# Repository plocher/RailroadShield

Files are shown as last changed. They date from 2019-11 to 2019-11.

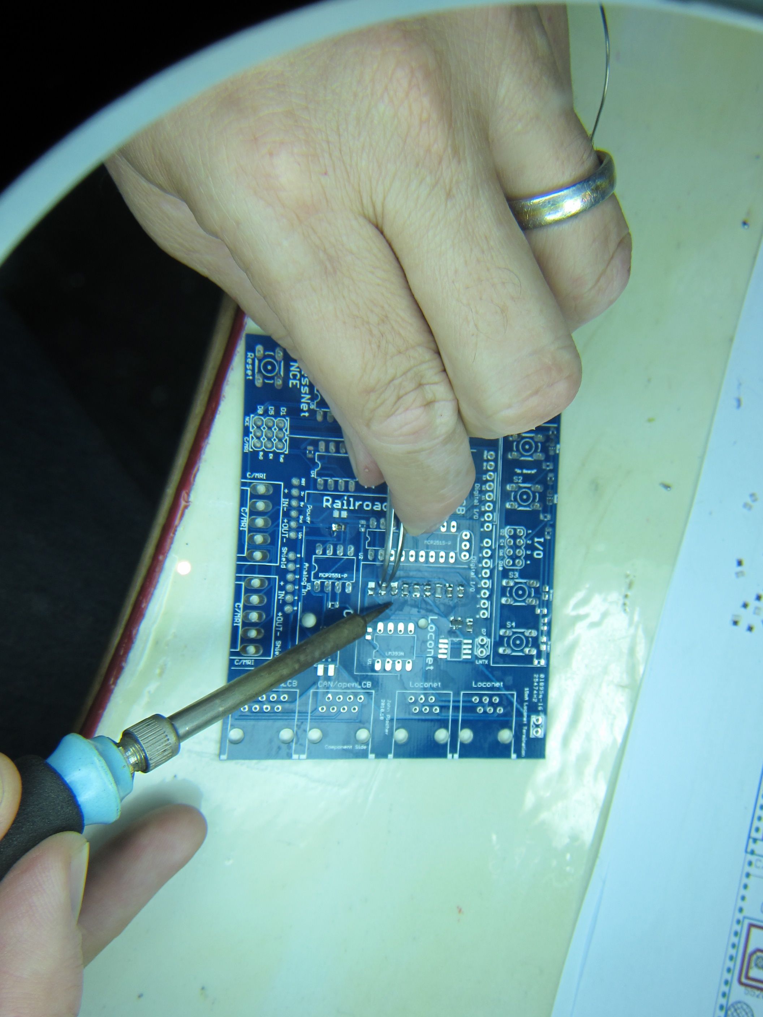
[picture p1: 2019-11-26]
RailroadShield-06.jpg

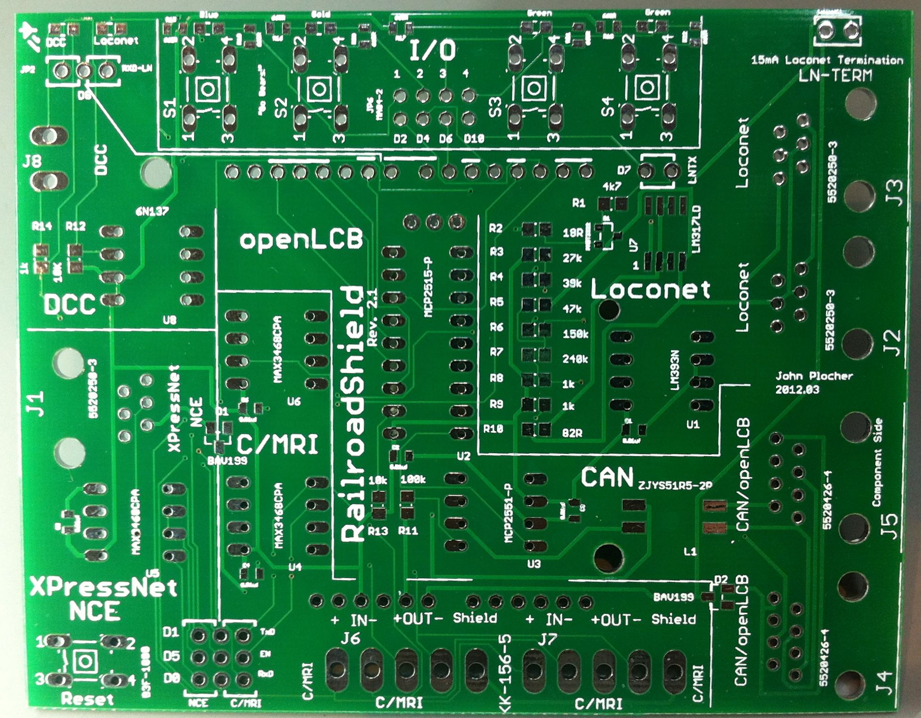
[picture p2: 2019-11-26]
RailroadShield-13.jpg

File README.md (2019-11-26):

# RailroadShield
## License: CERN Open Hardware Licence v1.2

A community prototyping board to help with the bringup and maturation of OpenLCB.

Status: Prototypes fab'd and assembled, runs simple OpenLCB sketches, more testing underway in the OpenLCB community...

This project is an Arduino shield for Loconet, CAN and
[http://www.olcb.org/ OpenLCB] experimentation.  It is based on an
earlier set of experiments that only supported CAN and Loconet as
part of a custom 'duino stack which was used to build a [[ControlPoint]]
demo for the PCR Coast Division meet early in September, 2010.

I also spun solderless breadboard versions of the CANBusBreadboard
and LoconetBreadboard; the Loconet board works fine, but I have not
yet (2010) built and tested the CAN board.

The prototype served its purpose - it helped prove out the design
pattern of a local control point node that uses a local Loconet to
monitor occupancy detectors, turnouts and other "vital" logic as
well as control signals associated with the interlocking.  I built
a small handful of 8- and 16-bit I2C based I/O expander boards
(think mini-C/MRI) to make interfacing with control panels and LEDs
easier, but the power draw of 30 to 60 LEDs - even at 10mA ea - is
almost too much for the simple heatsinked 7805 linear regulator I
designed into the main board.  Better to use a distributed power
supply design, which means another design/fab cycle and more boards
in my junk drawer :-)

As in the real world, the control point passed Controls and Indications
back and forth along a code line; in the 1.0 demo, I used OPC_PEER_XFER
Loconet packets to emulate a code line; the next step is to use
CAN/openLCB instead.

The RailroadShield board is based on an expanded footprint Arduino
Shield template so that Decimila, Uno and Duemilanove boards can
easily be used with it.

This design has hardware support for

  * DCC  on D8,
  *  * See [http://www.nmra.org/standards/DCC/standards_rps/DCCStds.html NMRA DCC Standards] documentation
  * Loconet (RXD on D8, Lnet TXD on D7)
  *  * See Digitrax's [Loconet Personal Edition](http://www.digitrax.com/ftp/loconetpersonaledition.pdf)
  * CAN/openLCB using MCP2515 & MCP2551 on D13-D11,D9 & D3
  *  * See [OpenLCB info](http://openlcb.org/trunk/prototypes/Hobbyists.html)
  * RS485 full duplex/2 wire (NCE & XPressNet) or half duplex/4 wire (C/MRI) using the built in UART on D0/D1 with TX enable on D5
  *  * See Lenz's XpressNet: [Specification](http://www.lenz.com/manuals/xpressnet/xpressnet.pdf) and
  *  * NCE's cab bus [on page 32 of the Power Pro System Reference Manual](http://www.ncedcc.com/images/stories/manuals/sysman07.pdf)
  * 4 buttons+LEDs for simple I/O testing.

Let me know if you develop sketches or libraries for the above and
I will update this page with links.  Better yet, contribute the
code back to the openlcb.org openLCB project.

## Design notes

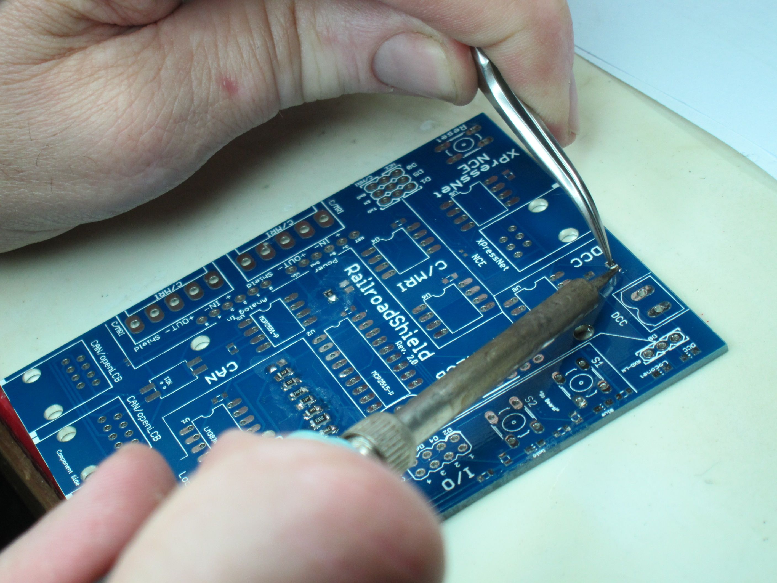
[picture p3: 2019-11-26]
RailroadShield-09.jpg

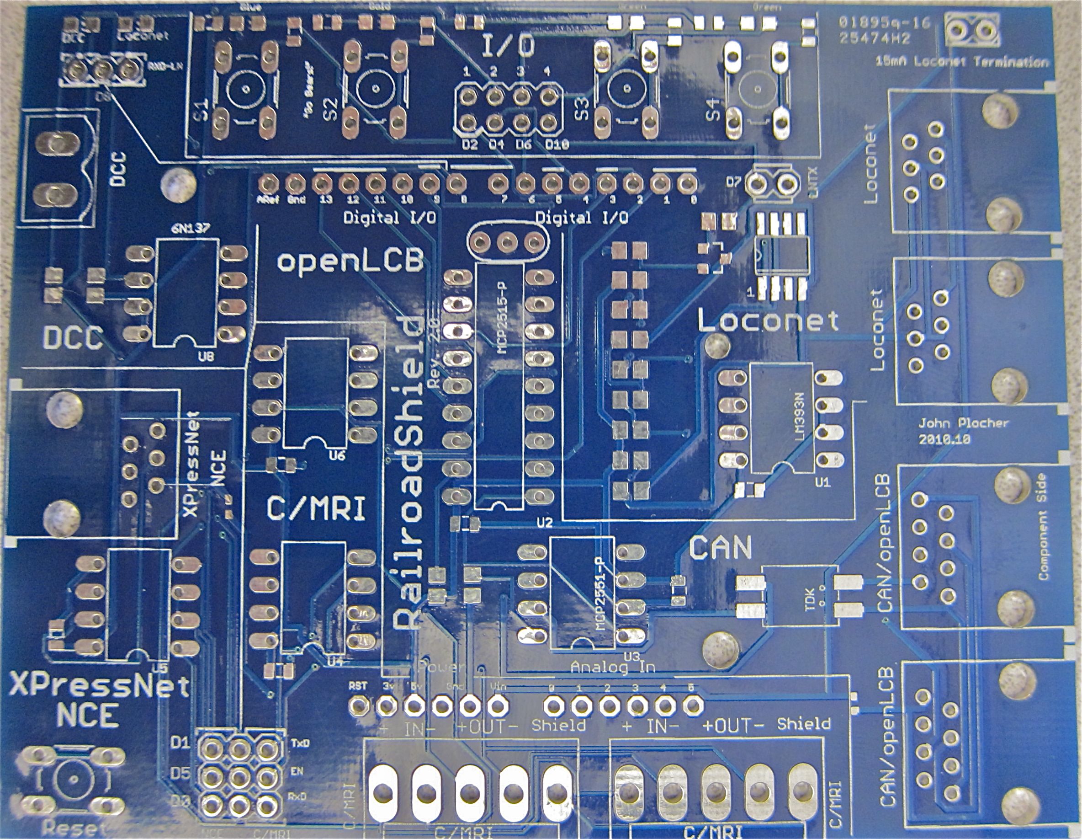
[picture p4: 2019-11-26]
RailroadShield-03.jpg

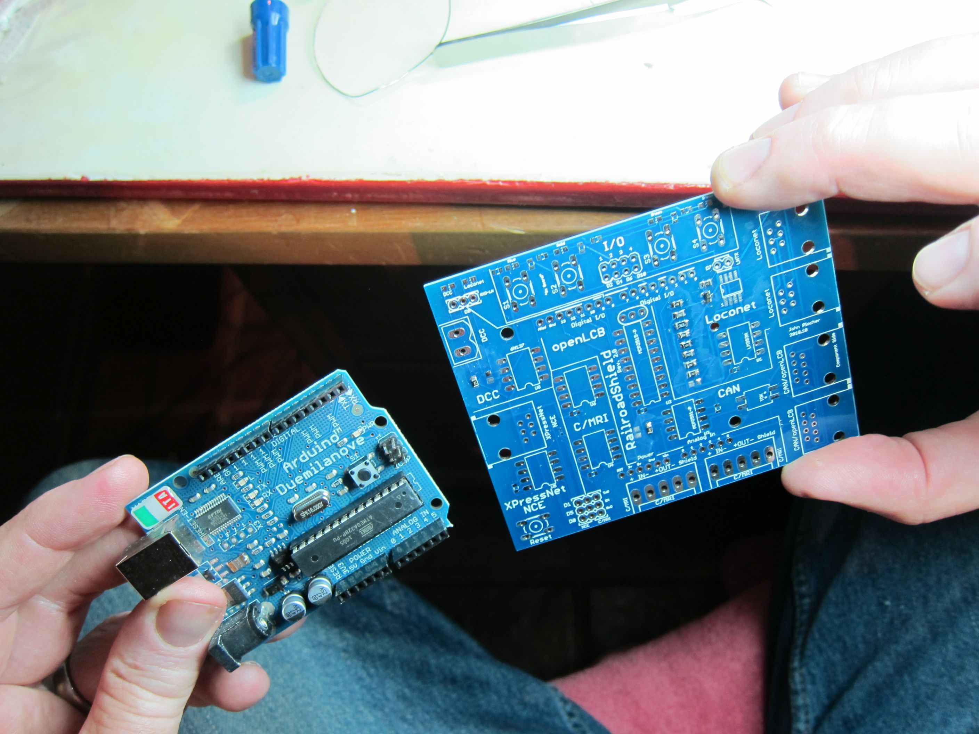
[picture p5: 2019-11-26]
RailroadShield-08.jpg

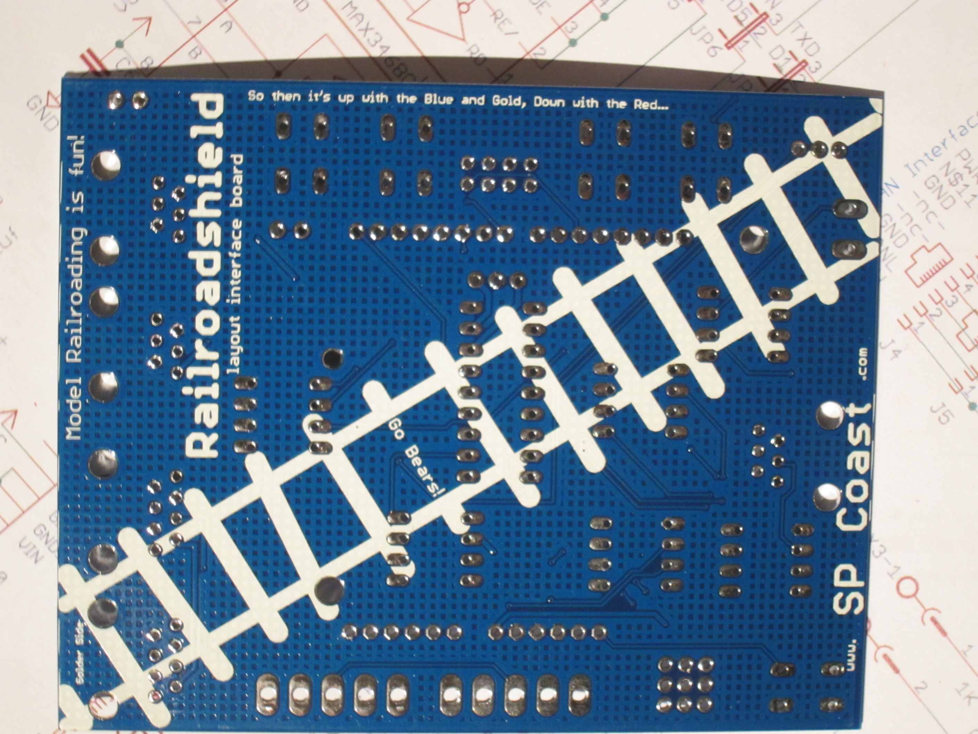
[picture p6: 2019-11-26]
RailroadShield-11.jpg

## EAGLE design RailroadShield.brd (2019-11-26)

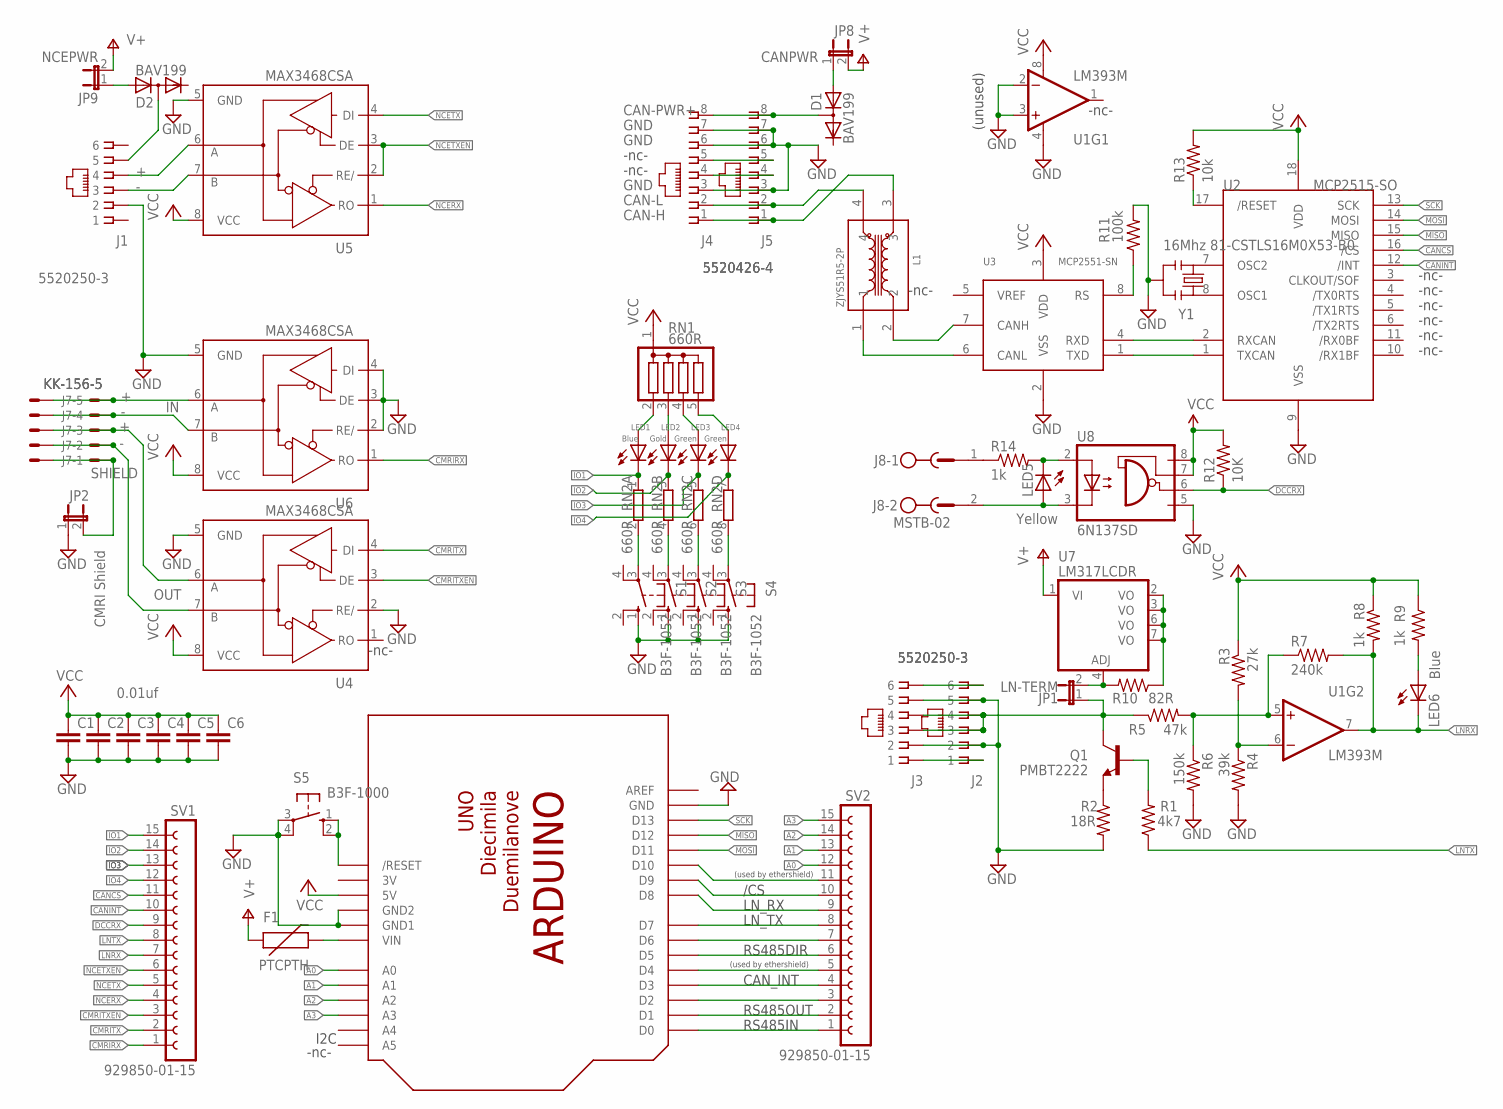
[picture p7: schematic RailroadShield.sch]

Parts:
C1, C2, C3, C4, C5, C6: 0.01uf; 0805
D1, D2: BAV199; SOT23
F1: PTCPTH; PTC
J1, J2, J3: 5520250-3; RJ11-NO_SHIELD
J4, J5: 5520426-4; RJ45-NO-SHIELD
J6, J7: KK-156-5
J8: MSTB-02; MSTBV2
JP1: LN-TERM; 1X02_LOCK
JP2: CMRI Shield; 1X02_LOCK
JP8: CANPWR; 1X02_LOCK
JP9: NCEPWR; 1X02_LOCK
L1: ZJYS51R5-2P; ZJYS
LED1, LED6: Blue; CHIP-LED0805
LED2: Gold; CHIP-LED0805
LED3, LED4: Green; CHIP-LED0805
LED5: Yellow; CHIP-LED0805
Q1: PMBT2222; SOT23-3
R1: 4k7; R0805
R2: 18R; R0805
R3: 27k; R0805
R4: 39k; R0805
R5: 47k; R0805
R6: 150k; R0805
R7: 240k; R0805
R8, R9, R14: 1k; R0805
R10: 82R; R0805
R11: 100k; R0805
R12: 10K; R0805
R13: 10k; R0805
RN1: 660R; SIL5
RN2: 660R; SIL8
S1, S2, S3, S4: B3F-1052; B3F-10XX
S5: B3F-1000; B3F-10XX
SV1, SV2: 929850-01-15; FE15
U1: LM393M; SO08
U2: MCP2515-SO; SO-18W
U3: MCP2551-SN; SO-08
U4, U5, U6: MAX3468CSA; SO08
U7: LM317LCDR; SO08
U8: 6N137SD; SM8
U$1: ARDUINODUEMILANOVE; ARDUINO-BIGSHIELD
Y1: 16Mhz 81-CSTLS16M0X53-B0; RESONATOR-PTH

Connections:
3V: U$1.3V
/RESET: R13.1, U2.17 (/RESET)
A0: SV2.12, U$1.A0
A1: SV2.13, U$1.A1
A2: SV2.14, U$1.A2
A3: SV2.15, U$1.A3
A/RESET: S5.1 (S), S5.2 (S1), U$1.RESET (/RESET)
CAN-H: J4.1, J5.1, L1.3
CAN-L: J4.2, J5.2, L1.4
CAN-PWR+: D1.3 (AC), J4.8, J5.8
CANCS: SV1.11, U2.16 (/CS)
CANH: L1.2, U3.7 (CANH)
CANINT: SV1.10, U2.12 (/INT)
CANL: L1.1, U3.6 (CANL)
CMRIRX: SV1.1, U6.1 (RO)
CMRITX: SV1.2, U4.4 (DI)
CMRITXEN: SV1.3, U4.3 (DE)
D0: SV2.1, U$1.D0
D1: SV2.2, U$1.D1
D2: SV2.3, U$1.D2
D3: SV2.4, U$1.D3
D4: SV2.5, U$1.D4
D5: SV2.6, U$1.D5
D6: SV2.7, U$1.D6
D7: SV2.8, U$1.D7
D8: SV2.9, U$1.D8
D9: SV2.10, U$1.D9
D10: SV2.11, U$1.D10
DCC-A: LED5.C, R14.2, U8.2 (A)
DCCB: J8.2, LED5.A, U8.3 (C)
DCCRX: R12.1, SV1.9, U8.6 (VO)
GND: C1.2, C2.2, C3.2, C4.2, C5.2, C6.2, J1.2, J2.2, J2.5, J3.2, J3.5, J4.3, J4.6, J4.7, J5.3, J5.6, J5.7, JP2.1, R2.2, R4.2, R6.2, R11.2, S1.1 (S), S2.1 (S), S3.1 (S), S4.1 (S), S5.3, S5.4 (P1), U1.2 (-IN), U1.3 (+IN), U1.4 (V-), U2.9 (VSS), U3.2 (VSS), U4.2 (RE/), U4.5 (GND), U5.5 (GND), U6.2 (RE/), U6.3 (DE), U6.4 (DI), U6.5 (GND), U8.5 (GND), U$1.GND, U$1.GND1, U$1.GND2, Y1.2
IO1: LED1.C, RN2.1, SV1.15
IO2: LED2.C, RN2.3 (1), SV1.14
IO3: LED3.C, RN2.5 (1), SV1.13
IO4: LED4.C, RN2.7 (1), SV1.12
L6+: LED6.A, R9.2
LN-TX: Q1.1 (B), R1.2
LNRX: LED6.C, R7.2, R8.2, SV1.7, U1.7 (OUT)
LNTX: R1.1, SV1.8
LOCONET: J2.3, J2.4, J3.3, J3.4, JP1.1, Q1.3 (C), R5.1
LOCONET-IN: R5.2, R6.1, R7.1, U1.5 (+IN)
MISO: U2.15 (MISO), U$1.D12
MOSI: U2.14 (MOSI), U$1.D11
unnamed: Q1.2 (E), R2.1
unnamed: LED1.A, RN1.2
unnamed: LED2.A, RN1.3
unnamed: LED3.A, RN1.4
unnamed: LED4.A, RN1.5
unnamed: J6.1, J7.1, JP2.2
unnamed: J6.2, J7.2, U4.7 (B)
unnamed: J6.3, J7.3, U4.6 (A)
unnamed: J6.4, J7.4, U6.7 (B)
unnamed: J6.5, J7.5, U6.6 (A)
unnamed: J8.1, R14.1
unnamed: U2.8 (OSC1), Y1.3
unnamed: U2.7 (OSC2), Y1.1
unnamed: D2.1 (A), JP9.1
unnamed: D1.1 (A), JP8.1
unnamed: RN2.2, S1.3
unnamed: RN2.4 (2), S2.3
unnamed: RN2.6 (2), S3.3
unnamed: RN2.8 (2), S4.3
unnamed: JP1.2, R10.2, U7.4 (ADJ)
unnamed: F1.P$2 (2), U$1.VIN
N-A: J1.4, U5.6 (A)
N-B: J1.3, U5.7 (B)
NCE-PWR+: D2.3 (AC), J1.5
NCERX: SV1.4, U5.1 (RO)
NCETX: SV1.5, U5.4 (DI)
NCETXEN: SV1.6, U5.2 (RE/), U5.3 (DE)
O-RESA: J4.4, J5.4
O-RESB: J4.5, J5.5
RAILSYNCA: J2.6, J3.6
RAILSYNCB: J2.1, J3.1
RS: R11.1, U3.8 (RS)
RXCAN: U2.2 (RXCAN), U3.4 (RXD)
SCK: U2.13 (SCK), U$1.D13
TXCAN: U2.1 (TXCAN), U3.1 (TXD)
V+: F1.P$1 (1), JP8.2, JP9.2, U7.1 (VI)
V-LNREF: R3.2, R4.1, U1.6 (-IN)
VCC: C1.1, C2.1, C3.1, C4.1, C5.1, C6.1, R3.1, R8.1, R9.1, R12.2, R13.2, RN1.1, U1.8 (V+), U2.18 (VDD), U3.3 (VDD), U4.8 (VCC), U5.8 (VCC), U6.8 (VCC), U8.7 (VE), U8.8 (VCC), U$1.5V
VOUT: R10.1, U7.2 (VO), U7.3 (VO), U7.6 (VO), U7.7 (VO)

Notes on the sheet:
-nc-
(unused)
/CS
LN_RX
LN_TX
CAN_INT
RS485IN
RS485OUT
RS485DIR
OUT
SHIELD
(used by ethershield)
I2C

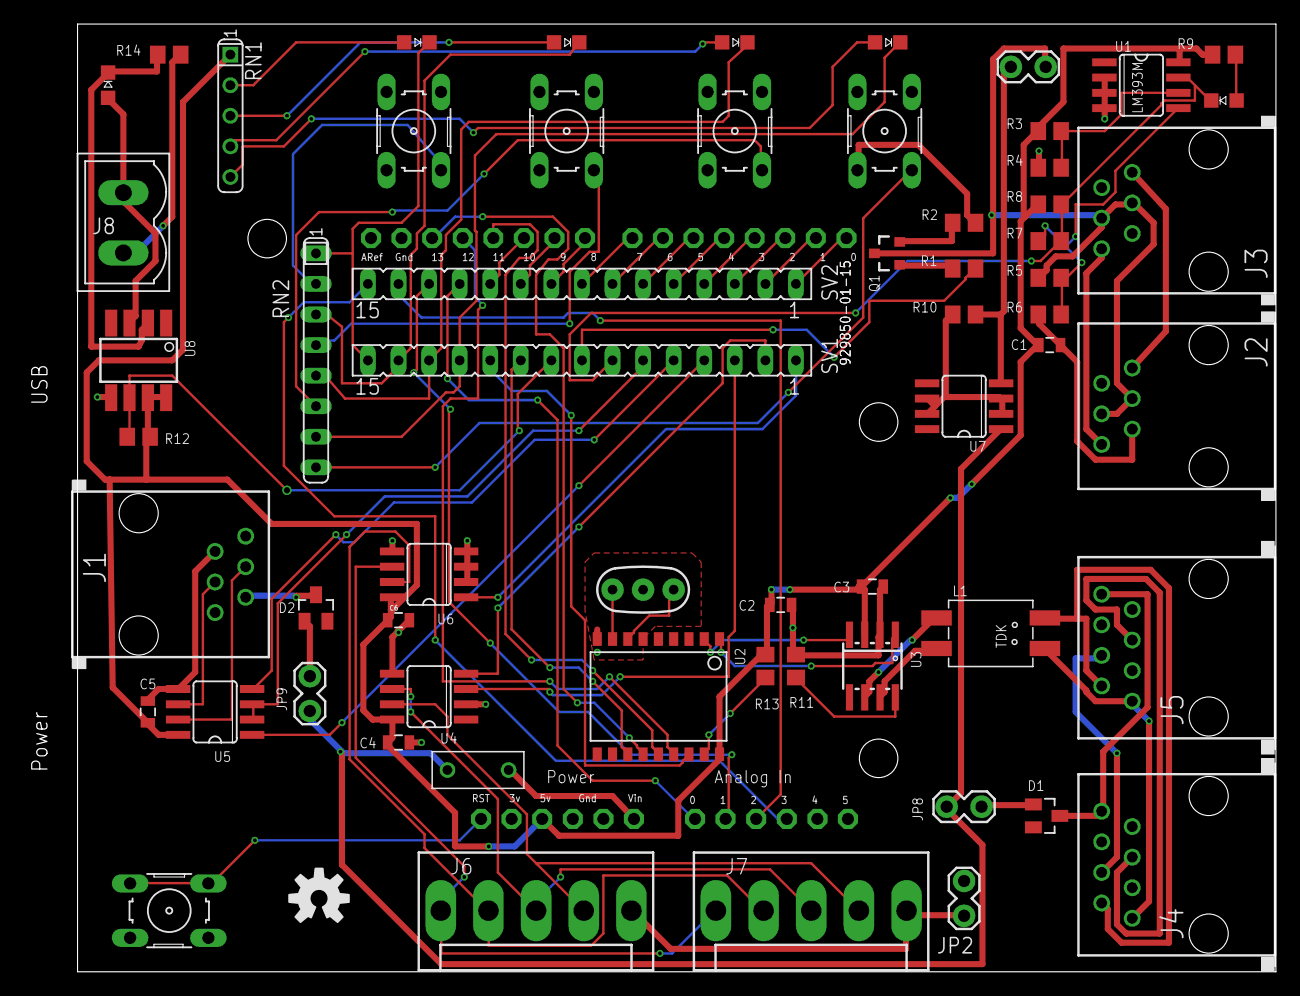
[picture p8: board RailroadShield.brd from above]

Board: 2 copper layers, 99.6 x 78.7 mm, 63 parts (0 on the bottom side), 82 nets.

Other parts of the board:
U$2: OSHW-LOGOM; OSHW-LOGO-M
